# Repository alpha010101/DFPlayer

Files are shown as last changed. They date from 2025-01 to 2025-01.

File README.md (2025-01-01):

###
市販されているMP3プレイヤーユニット"DFPlayer mini"2個を載せるための基板。外部のマイコンからUARTでコマンドを送って操作することを想定。UARTの接続はPHコネクタ。

基板上のスイッチは「Start/Pause」「Next/Volum+」「Prev/Volume-」の3種類を2系統それぞれに設ける。この制御用の端子は外に引き出せるようなパターンになっている。出力はDFPlayer-miniに載っているアンプを通したモノラル出力をスピーカー端子に、アンプを通さないDACのステレオ出力を3.5mmステレオジャックに出している。この基板に電源を入れれば単体で動作する。基板上は電源が5Vとなっているが、搭載されているICとしては3.3Vが正しいので注意を（5Vはほぼ仕様上の限界で、4.8Vくらいに留めるほうが良いとも言われている）

テスト用に集めたDFPlayer-miniだが、1個は以前に秋月で買ったもの、1個は今回秋月で買ったもの、2個は今回Amazonで買ったもので、3種類ともUARTコマンドに対する動作や、DACの出力や、動作LEDの色など色々と違いがあり、考えていた操作ができなかった。このあたり、まとめる時間があれば追記するかもしれない。

動かしてみた感想としては、ブレッドボードで鳴らすよりかなり音が良く、特にDAC出力の3.5mmステレオジャックからの出力は期待以上の音質であった

SchematicとPCB-LayoutはAutodesk-Eagle無償版で作成し、elecrowで製造することを念頭にガーバーを作成している

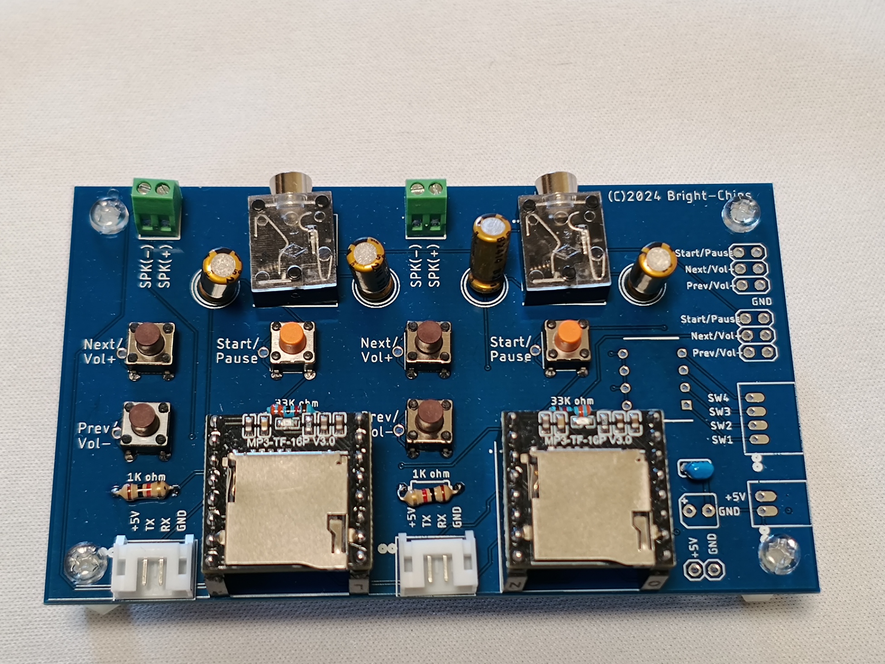
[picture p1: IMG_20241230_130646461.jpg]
DFPlayer-mini board


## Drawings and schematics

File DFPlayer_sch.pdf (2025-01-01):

A

A

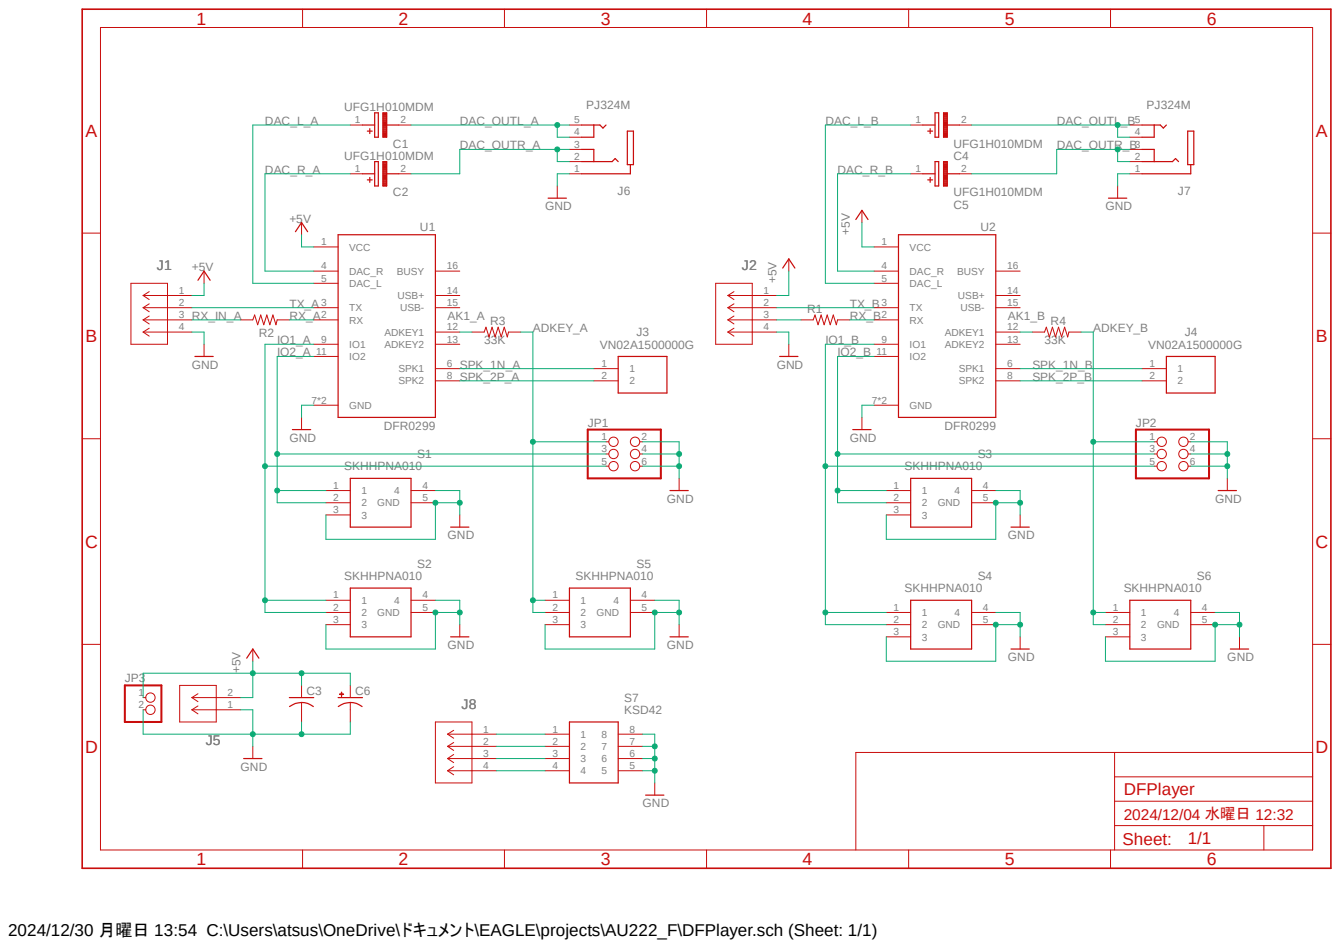
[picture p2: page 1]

2024/12/30 月曜日 13:54 C:\Users\atsus\OneDrive\ドキュメント\EAGLE\projects\AU222_F\DFPlayer.sch (Sheet: 1/1)

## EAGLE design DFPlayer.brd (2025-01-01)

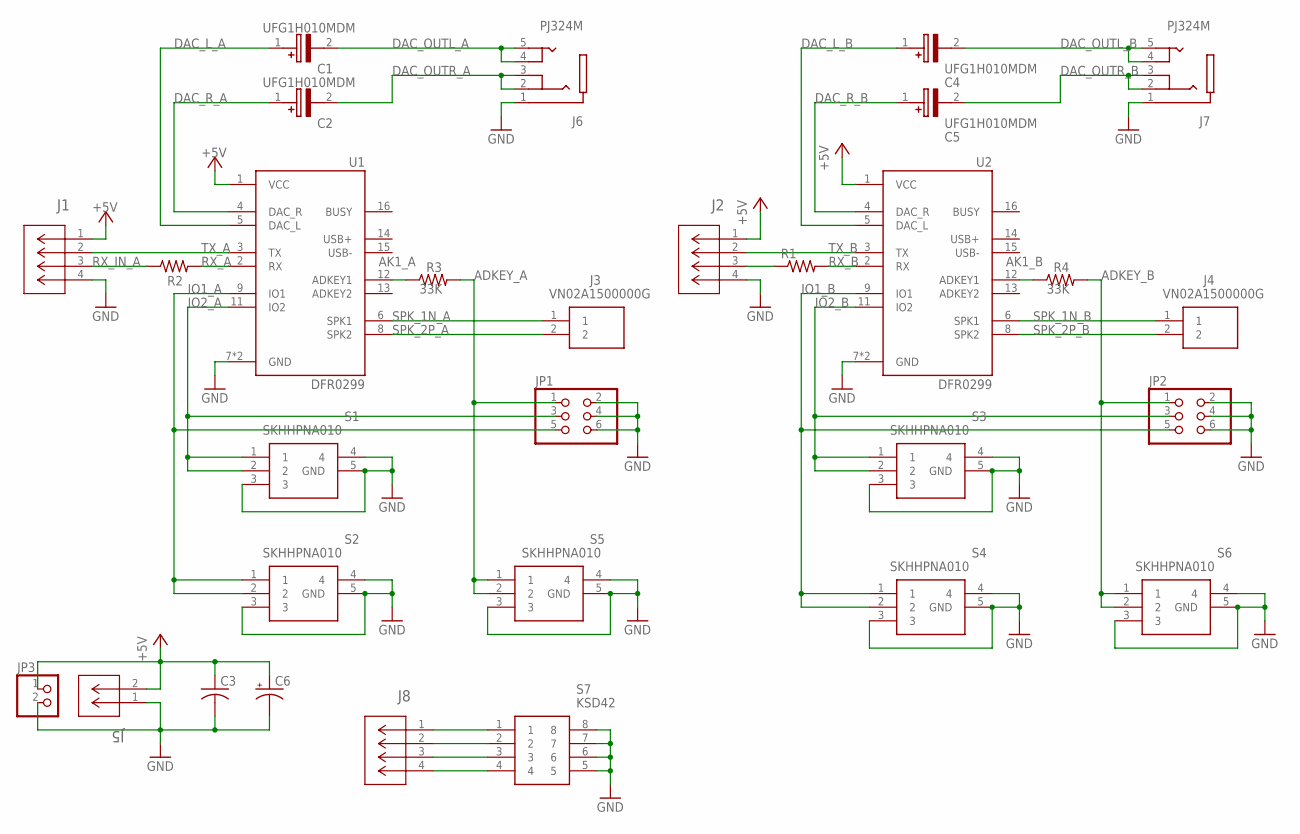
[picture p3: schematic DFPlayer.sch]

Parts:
C1, C2, C4, C5: UFG1H010MDM; CAPPRD200W60D550H1250
C3: C-US025-024X044; C025-024X044
C6: CPOL-USB45181A; B45181A
J1, J2, J8: S4B-PH-K-S(LF)(SN); CONN_S4B-PH-K-S_JST
J3, J4: VN02A1500000G
J5: S2B-PH-K-S(LF)(SN); CONN_S2B-PH-K-S_JST
J6, J7: PJ324M; WENZHOU_PJ324M
JP1, JP2: PINHD-2X3; 2X03
JP3: PINHD-1X2; 1X02
R1, R2, R3, R4: R-US_0204/7; 0204/7
S1, S2, S3, S4, S5, S6: SKHHPNA010; SKHHPJA010
S7: KSD42; DIP815W60P254L1210H450Q8N
U1, U2: DFR0299; MODULE_DFR0299

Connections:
+5V: C3.1, C6.+, J1.1, J2.1, J5.2, JP3.1, U1.1 (VCC), U2.1 (VCC)
ADKEY_A: JP1.1, R3.2, S5.1, S5.2
ADKEY_B: JP2.1, R4.2, S6.1, S6.2
AK1_A: R3.1, U1.12 (ADKEY1)
AK1_B: R4.1, U2.12 (ADKEY1)
DAC_L_A: C1.1 (+), U1.5 (DAC_L)
DAC_L_B: C4.1 (+), U2.5 (DAC_L)
DAC_OUTL_A: C1.2 (-), J6.4 (TIP_1), J6.5 (TIP_2)
DAC_OUTL_B: C4.2 (-), J7.4 (TIP_1), J7.5 (TIP_2)
DAC_OUTR_A: C2.2 (-), J6.2 (RING_1), J6.3 (RING_2)
DAC_OUTR_B: C5.2 (-), J7.2 (RING_1), J7.3 (RING_2)
DAC_R_A: C2.1 (+), U1.4 (DAC_R)
DAC_R_B: C5.1 (+), U2.4 (DAC_R)
GND: C3.2, C6.-, J1.4, J2.4, J5.1, J6.1 (SLEEVE), J7.1 (SLEEVE), JP1.2, JP1.4, JP1.6, JP2.2, JP2.4, JP2.6, JP3.2, S1.3, S1.4, S1.5 (GND), S2.3, S2.4, S2.5 (GND), S3.3, S3.4, S3.5 (GND), S4.3, S4.4, S4.5 (GND), S5.3, S5.4, S5.5 (GND), S6.3, S6.4, S6.5 (GND), S7.5, S7.6, S7.7, S7.8, U1.7 (GND), U1.10 (GND), U2.7 (GND), U2.10 (GND)
IO1_A: JP1.5, S2.1, S2.2, U1.9 (IO1)
IO1_B: JP2.5, S4.1, S4.2, U2.9 (IO1)
IO2_A: JP1.3, S1.1, S1.2, U1.11 (IO2)
IO2_B: JP2.3, S3.1, S3.2, U2.11 (IO2)
unnamed: J8.1, S7.1
unnamed: J8.2, S7.2
unnamed: J8.3, S7.3
unnamed: J8.4, S7.4
unnamed: J2.3, R1.1
RX_A: R2.2, U1.2 (RX)
RX_B: R1.2, U2.2 (RX)
RX_IN_A: J1.3, R2.1
SPK_1N_A: J3.1, U1.6 (SPK1)
SPK_1N_B: J4.1, U2.6 (SPK1)
SPK_2P_A: J3.2, U1.8 (SPK2)
SPK_2P_B: J4.2, U2.8 (SPK2)
TX_A: J1.2, U1.3 (TX)
TX_B: J2.2, U2.3 (TX)

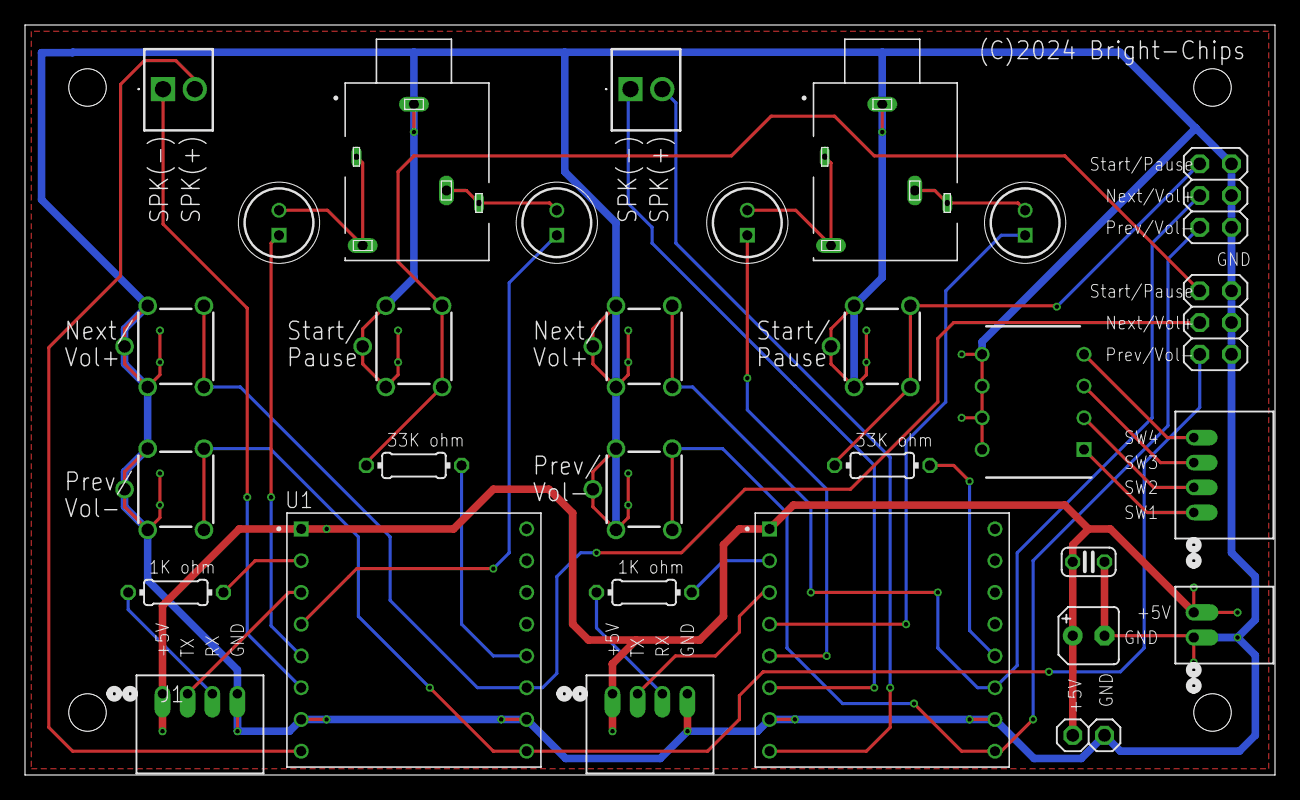
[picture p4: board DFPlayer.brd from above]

Board: 2 copper layers, 100.0 x 60.0 mm, 30 parts (0 on the bottom side), 32 nets.

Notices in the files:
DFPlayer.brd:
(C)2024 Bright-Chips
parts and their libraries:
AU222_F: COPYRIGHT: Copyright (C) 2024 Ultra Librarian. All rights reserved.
